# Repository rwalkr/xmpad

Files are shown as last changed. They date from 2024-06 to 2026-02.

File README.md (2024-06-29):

# xmpad - Meeting macropad

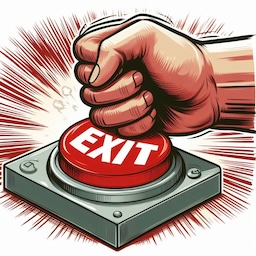
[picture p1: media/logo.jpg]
Exit


Spending too much time in meetings?  Want to exit quickly? Then you need this!

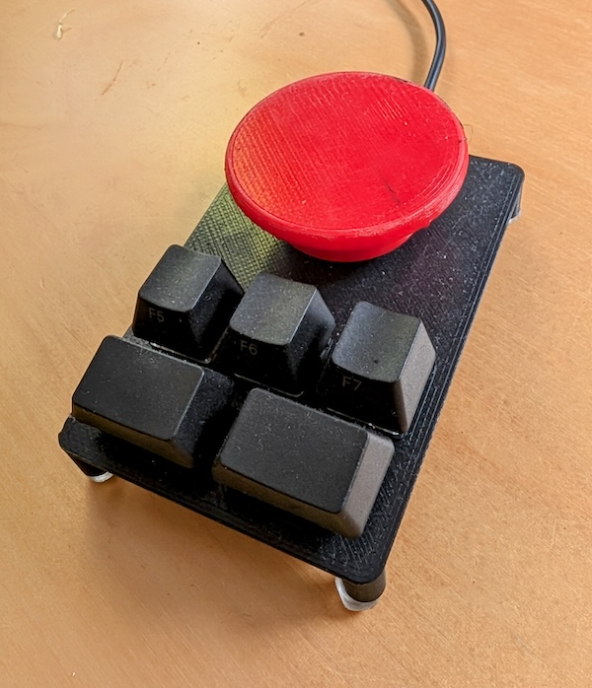
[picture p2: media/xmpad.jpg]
xmpad


Hit the red to button to exit immediately.  Also has buttons for audio mute and video on/off.

xmpad can be configured to emit custom keypresses for each button - change these to fit your meeting software.  The default maps are:

* Red button: Exit - Ctrl+Alt+F12
* Front left: Audio on/off - Ctrl+Alt+F10
* Front right: Video on/off - Ctrl+Alt+F11
* Middle left: Window switch - Alt+Tab
* Middle centre: Close window - Alt+F4
* Middle right: Enter

I've configured global shortcuts in Zoom for these buttons to avoid clashes with other apps.

xmpad is controlled by a Raspberry Pi Pico connected via USB which appears on your computer as an additonal keyboard.  The key switches are standard MX switches, with MX keycaps.  The big red button is glued on top of a MX keycap.

## Build instructions

### Firmware

The firmware is written in rust.  Install the `thumbv6m-none-eabi` toolchain and compile with:

```
cd firmware
cargo build --release
```

Then install by plugging in the Pico in boot mode and running:

```
elf2uf2-rs -d target/thumbv6m-none-eabi/release/xmpad
```

### 3D Print

Print the case and button from the files in `case/`

### BOM

* Printed case and button
* Raspberry Pi Pico
* Micro USB cable
* 6x MX compatible key switches
* 6x MX keycaps (2x 1.5U, 4x 1U)
* Wire
* Screws to attach Pico
* 4x rubber feet

### Wiring

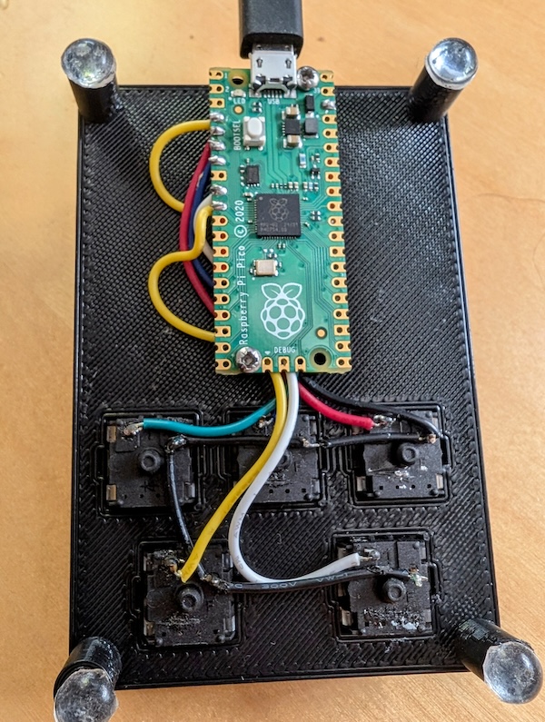
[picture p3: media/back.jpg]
Wiring


* Wire a ground wire across all switches to pin 30 (GND)
* Red button: wire to pin 4 (GPIO2)
* Middle left: wire to pin 5 (GPIO3)
* Middle centre: wire to pin 6 (GPIO4)
* Middle right: wire to pin 7 (GPIO5)
* Front left: wire to pin 9 (GPIO6)
* Front right: wire to pin 10 (GPIO7)

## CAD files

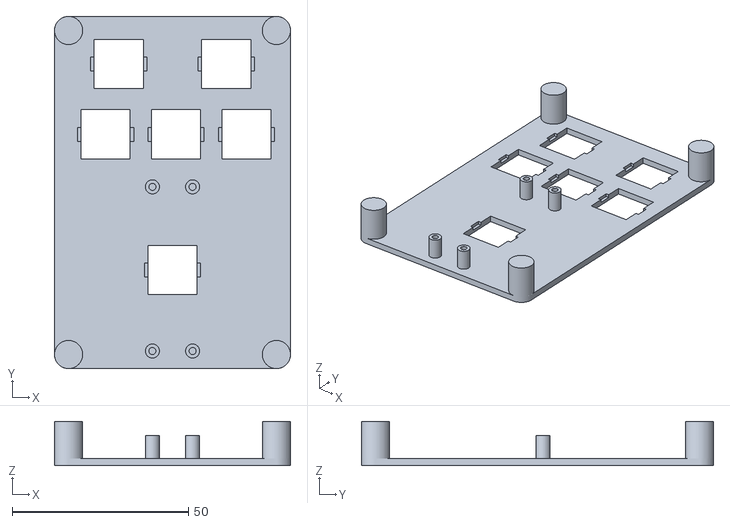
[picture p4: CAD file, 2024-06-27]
case/xmpad.stl
67.0 x 100.0 x 12.5

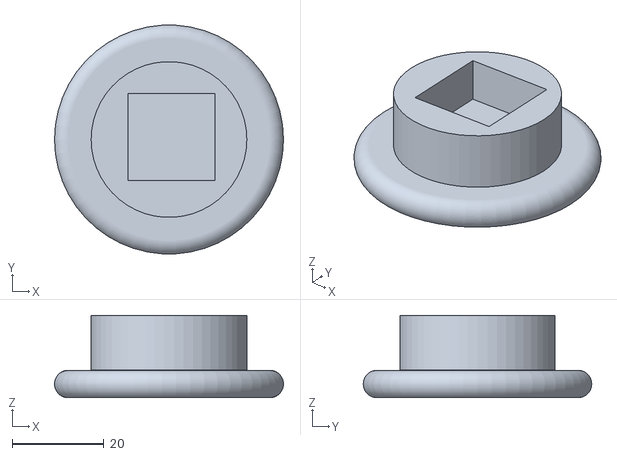
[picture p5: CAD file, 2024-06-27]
case/xmpad_button.stl
50.0 x 49.9 x 18.0

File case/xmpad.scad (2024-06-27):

include <BOSL/constants.scad>
use <BOSL/shapes.scad>

$fn = 50;

U = 19;
K = 14;
KH = 6.5;

SB_D = 50;
SB_T = 6;
SB_H = 18;

PW = 4 + 3*U + 2 + 4;
PD = 4 + 2 * U + 1 + 3 + SB_D + 4;
PH = KH + 4;
PT = 2;

module stop_button () {
  translate([0, 0, SB_H])
  rotate([180, 0, 0])
  color("red") {
    difference() {
      union() {
        //cylinder(h = 6, d = SB_D);
        cyl(h = SB_T, d = SB_D, fillet=3, chamfer = 0, center=false);
        translate([0, 0, SB_T])
          cylinder(r = 17, h = SB_H-SB_T);
      }
      
      translate([-9, -9, SB_H-9])
        cube([19, 19, 9.1]);
    }
  }
}


module key_hole () {
  color("green", 0.1) {
  translate([-K/2, -K/2, -0.1 - 8 + PT]) {
    cube([K, K, 8.2]);
    translate([K/2-2, -1, 6])
      cube([4, K+2, 1.1]);
  }
  }
}

module key_cap (n) {
  color("yellow", 0.6)
  //translate([-n * U / 2, -U / 2, 0])
  prismoid(size1=[n * U, U], size2=[n * U - 4, U - 4], h=8);
//  cube([n * U, U, 8]);
}

module plate () {
    difference() {
      color("blue")
      union() {
        cuboid([PW, PD, 2], fillet=4, edges=EDGES_Z_ALL, center=false);
      }
      
      translate([0, 3 + 1 + 0.5 * U, 0]) {
        translate([4 + 0.75 * U, 0, 0])
          key_hole();
        translate([PW - 4 -  0.75 * U, 0, 0])
          key_hole();
      }
      translate([4, 3 + 1 + U + 1 + 0.5 * U, 0]) {
        translate([0.5 * U, 0, 0])
          key_hole();
        translate([U + 1 + 0.5 * U, 0, 0])
          key_hole();
        translate([2 * U + 2 + 0.5 * U, 0, 0])
          key_hole();
      }
      translate([PW/2, PD - 3 - SB_D/2, 0])
        key_hole();
    }
}

module feet () {
  color("yellow") {
    cube([PW, 3, PH]);
    translate([0, PD - 3, 0])
      difference() {
        cube([PW, 3, PH]);
        translate([PW/2 - 4, -0.1, -0.1])
          cube([8, 3.2, PH - KH + 0.1]);
      }
  }
}

module legs () {
  color("yellow") {
    translate([4, 4, 0])
       cylinder(h = PH, r = 4);
    translate([PW-4, 4, 0])
       cylinder(h = PH, r = 4);
    translate([4, PD-4, 0])
       cylinder(h = PH, r = 4);
    translate([PW-4, PD-4, 0])
       cylinder(h = PH, r = 4);
  }
}

module post () {
   translate([0, 0, PH - KH])
     difference() {
       cylinder(h = KH, d = 4);
       translate([0, 0, -0.1])
       cylinder(h = 3.1, d = 2);
     }
}

module posts () {
  translate([PW/2 - 5.7, PD - 3 - 2, 0])
    post();
  translate([PW/2 + 5.7, PD - 3 - 2, 0])
    post();
  translate([PW/2 - 5.7, PD - 3 - 48.6, 0])
    post();
  translate([PW/2 + 5.7, PD - 3 - 48.6, 0])
    post();
}

  
module pad () {
    translate([0, 0, -PT]) {
      plate();
      translate([0, 0, -PH]) {
        legs();
        posts();
      }
    }
}
  
module preview () {
  translate([PW/2, PD - 3 - SB_D/2, 5])
     stop_button();
  pad();
  
  translate([0, 3 + 1 + 0.5 * U, 2]) {
    translate([4 + 0.75 * U, 0, 0])
      key_cap(1.5);
    translate([PW - 4 -  0.75 * U, 0, 0])
      key_cap(1.5);
    }
  translate([4, 3 + 1 + U + 1 + 0.5 * U, 2]) {
    translate([0.5 * U, 0, 0])
      key_cap(1);
    translate([U + 1 + 0.5 * U, 0, 0])
      key_cap(1);
    translate([2 * U + 2 + 0.5 * U, 0, 0])
      key_cap(1);
  }

}


module print_button () {
  rotate([180, 0, 0])
  stop_button();
}

module print_pad() {
  rotate([180, 0, 0])
  pad();
}


print_pad();
//print_button();
//preview();

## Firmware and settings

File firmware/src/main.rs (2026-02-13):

#![no_std]
#![no_main]

use core::sync::atomic::{AtomicBool, Ordering};

use defmt::*;
use embassy_executor::Spawner;
use embassy_futures::select::{select, Either};
use embassy_rp::bind_interrupts;
use embassy_rp::gpio::{Input, Pull};
use embassy_rp::peripherals::{PIO0, USB};
use embassy_rp::{pio, usb};
use embassy_sync::blocking_mutex::raw::ThreadModeRawMutex;
use embassy_sync::channel::{Channel, Receiver, Sender};
use embassy_time::{block_for, Duration, Instant, Ticker, Timer};
use embassy_usb::class::hid::{
    self, HidReader, HidReaderWriter, HidWriter, ReportId, RequestHandler, State,
};
use embassy_usb::control::OutResponse;
use embassy_usb::{Builder, Config, Handler};
use packed_struct::prelude::*;
use static_cell::StaticCell;
use usbd_human_interface_device::{
    device::keyboard::{BootKeyboardReport, BOOT_KEYBOARD_REPORT_DESCRIPTOR},
    page::Keyboard,
};
use heapless::Vec;

use {defmt_rtt as _, panic_probe as _};

type KbdHidReaderWriter<'a> = HidReaderWriter<'a, usb::Driver<'a, USB>, 1, 25>;
type KbdHidReader<'a> = HidReader<'a, usb::Driver<'a, USB>, 1>;
type KbdHidWriter<'a> = HidWriter<'a, usb::Driver<'a, USB>, 25>;

#[derive(PartialEq)]
enum KbdEvent {
    Press,
    Release
}

type KbdEventQueue = Channel<ThreadModeRawMutex, KbdEvent, 4>;
type KbdEventQueueSender<'a> = Sender<'a, ThreadModeRawMutex, KbdEvent, 4>;
type KbdEventQueueReceiver<'a> = Receiver<'a, ThreadModeRawMutex, KbdEvent, 4>;
type KbdReportQueue = Channel<ThreadModeRawMutex, Keycodes, 4>;
type KbdReportQueueSender<'a> = Sender<'a, ThreadModeRawMutex, Keycodes, 4>;
type KbdReportQueueReceiver<'a> = Receiver<'a, ThreadModeRawMutex, Keycodes, 4>;

mod modifiers {
    pub const SHIFT: u32 = 1;
    pub const CTRL: u32 = 2;
    pub const ALT: u32 = 4;
    pub const GUI: u32 = 8;
}
type Modifiers = u32;

enum KeyAction {
    Simple{ key: Keyboard, m: Modifiers },
    StickyModifiers{ key: Keyboard, m: Modifiers, pre_delay: u64, release_delay: u64 }
}

const KEY_COUNT: usize = 6;
const KEY_ACTIONS: [KeyAction; KEY_COUNT] = [
    KeyAction::Simple { key: Keyboard::F12, m: modifiers::CTRL | modifiers::ALT },
    KeyAction::StickyModifiers { key: Keyboard::Tab, m:  modifiers::ALT, pre_delay: 0, release_delay: 500 },
    KeyAction::StickyModifiers { key: Keyboard::P, m: modifiers::GUI, pre_delay: 50, release_delay: 1000 },
    KeyAction::Simple { key: Keyboard::ReturnEnter, m: 0 },
    KeyAction::Simple { key: Keyboard::F10, m: modifiers::CTRL | modifiers::ALT },
    KeyAction::Simple { key: Keyboard::F11, m: modifiers::CTRL | modifiers::ALT },
];

const MAX_KEYS: usize = KEY_COUNT + 4;
type Keycodes = Vec<Keyboard, MAX_KEYS>;

bind_interrupts!(struct Irqs {
    USBCTRL_IRQ => usb::InterruptHandler<USB>;
    PIO0_IRQ_0 => pio::InterruptHandler<PIO0>;
});

#[embassy_executor::main]
async fn main(spawner: Spawner) {
    let p = embassy_rp::init(Default::default());
    let usb_driver = usb::Driver::new(p.USB, Irqs);

    let key_pins: [Input; KEY_COUNT] = [
        Input::new(p.PIN_2, Pull::Up),
        Input::new(p.PIN_3, Pull::Up),
        Input::new(p.PIN_4, Pull::Up),
        Input::new(p.PIN_5, Pull::Up),
        Input::new(p.PIN_6, Pull::Up),
        Input::new(p.PIN_7, Pull::Up),
    ];

    // Create embassy-usb Config
    // Test PID from https://pid.codes/1209/
    const VID: u16 = 0x1209;
    const PID: u16 = 0x0002;
    let mut config = Config::new(VID, PID);
    config.manufacturer = Some("rwalkr");
    config.product = Some("xmpad");
    config.serial_number = Some(env!("CARGO_PKG_VERSION"));
    config.max_power = 100;
    config.max_packet_size_0 = 64;

    // Create embassy-usb DeviceBuilder using the driver and config.
    // It needs some buffers for building the descriptors.
    static CONFIG_DESCRIPTOR: StaticCell<[u8; 256]> = StaticCell::new();
    let config_descriptor = CONFIG_DESCRIPTOR.init([0; 256]);
    static BOS_DESCRIPTOR: StaticCell<[u8; 256]> = StaticCell::new();
    let bos_descriptor = BOS_DESCRIPTOR.init([0; 256]);
    static MSOS_DESCRIPTOR: StaticCell<[u8; 256]> = StaticCell::new();
    let msos_descriptor = MSOS_DESCRIPTOR.init([0; 256]);
    static CONTROL_BUF: StaticCell<[u8; 64]> = StaticCell::new();
    let control_buf = CONTROL_BUF.init([0; 64]);

    static KBD_HANDLER: StaticCell<KeyboardHandler> = StaticCell::new();
    let kbd_handler = KBD_HANDLER.init(KeyboardHandler::new());

    static DEVICE_HANDLER: StaticCell<USBDeviceHandler> = StaticCell::new();
    let device_handler = DEVICE_HANDLER.init(USBDeviceHandler::new());

    static KBD_HID_STATE: StaticCell<State> = StaticCell::new();
    let kbd_hid_state = KBD_HID_STATE.init(State::new());

    let mut builder = Builder::new(
        usb_driver,
        config,
        config_descriptor,
        bos_descriptor,
        msos_descriptor,
        control_buf,
    );
    builder.handler(device_handler);

    // Create classes on the builder.
    let kbd_hid_config = hid::Config {
        report_descriptor: BOOT_KEYBOARD_REPORT_DESCRIPTOR,
        request_handler: None,
        poll_ms: 60,
        max_packet_size: 64,
    };
    let kbd_hid = KbdHidReaderWriter::new(&mut builder, kbd_hid_state, kbd_hid_config);
    let (kbd_hid_reader, kbd_hid_writer) = kbd_hid.split();

    static KBD_EVENT_QUEUE: StaticCell<Vec<KbdEventQueue, KEY_COUNT>> = StaticCell::new();
    let kbd_event_queue = KBD_EVENT_QUEUE.init((0..KEY_COUNT).map(|_| Channel::new()).collect());
    let kbd_event_senders: Vec<KbdEventQueueSender, KEY_COUNT> = kbd_event_queue.iter().map(|q| q.sender()).collect();
    let kbd_event_receivers: Vec<KbdEventQueueReceiver, KEY_COUNT> = kbd_event_queue.iter().map(|q| q.receiver()).collect();

    static KBD_REPORT_QUEUE: StaticCell<KbdReportQueue> = StaticCell::new();
    let kbd_report_queue = KBD_REPORT_QUEUE.init(Channel::new());
    let kbd_report_sender = kbd_report_queue.sender();
    let kbd_report_receiver = kbd_report_queue.receiver();

    spawner.must_spawn(kbd_scan(key_pins, kbd_event_senders));
    for i in 0..KEY_COUNT {
        spawner.must_spawn(kbd_key_handler(&KEY_ACTIONS[i], kbd_event_receivers[i], kbd_report_sender));
    }
    spawner.must_spawn(kbd_hid_write(kbd_report_receiver, kbd_hid_writer));
    spawner.must_spawn(kbd_hid_read(kbd_hid_reader, kbd_handler));

    let mut usb = builder.build();
    usb.run().await;
}

struct KeyboardHandler {}

impl RequestHandler for KeyboardHandler {
    fn get_report(&mut self, id: ReportId, _buf: &mut [u8]) -> Option<usize> {
        info!("Get report for {:?}", id);
        None
    }

    fn set_report(&mut self, id: ReportId, data: &[u8]) -> OutResponse {
        info!("Set report for {:?}: {=[u8]}", id, data);
        OutResponse::Accepted
    }

    fn set_idle_ms(&mut self, id: Option<ReportId>, dur: u32) {
        info!("Set idle rate for {:?} to {:?}", id, dur);
    }

    fn get_idle_ms(&mut self, id: Option<ReportId>) -> Option<u32> {
        info!("Get idle rate for {:?}", id);
        None
    }
}

impl KeyboardHandler {
    fn new() -> KeyboardHandler {
        KeyboardHandler {}
    }
}

#[embassy_executor::task]
async fn kbd_scan(
    key_pins: [Input<'static>; KEY_COUNT],
    kbd_event_queues: Vec<KbdEventQueueSender<'static>, KEY_COUNT>
) {
    let mut ticker = Ticker::every(Duration::from_millis(1));
    const DEBOUNCE_TICKS: usize = 5;

    let mut pin_states = [false; KEY_COUNT];
    let mut pin_state_counts = [0; KEY_COUNT];
    let mut key_states = [false; KEY_COUNT];
    loop {
        // read pins and update states
        for p in 0..KEY_COUNT {
            let cur_state = key_pins[p].is_low();
            if pin_states[p] != cur_state {
                // pin has changed since last reading - reset counter
                pin_states[p] = cur_state;
                pin_state_counts[p] = 1;
            } else {
                // not changed
                pin_state_counts[p] += 1;
                if pin_state_counts[p] == DEBOUNCE_TICKS {
                    // steady state - update key state
                    info!("kbd_scan: Detected pin {}: {}", p, pin_states[p]);
                    key_states[p] = pin_states[p];
                    let ev = if pin_states[p] {
                        KbdEvent::Press
                    } else  {
                        KbdEvent::Release
                    };
                    kbd_event_queues[p].send(ev).await;
                }
            }
        }

        ticker.next().await;
    }
}

async fn wait_for_press(kbd_event_queue: &KbdEventQueueReceiver<'static>) {
    loop {
        let ev = kbd_event_queue.receive().await;
        if ev == KbdEvent::Press {
            break
        }
    }
}

async fn wait_for_release(kbd_event_queue: &KbdEventQueueReceiver<'static>) {
    loop {
        let ev = kbd_event_queue.receive().await;
        if ev == KbdEvent::Release {
            break
        }
    }
}

fn apply_modifiers(keycodes: &mut Keycodes, m: &Modifiers) {
    if m & modifiers::SHIFT != 0 {
        keycodes.push(Keyboard::LeftShift).unwrap()
    }
    if m & modifiers::CTRL != 0 {
        keycodes.push(Keyboard::LeftControl).unwrap()
    }
    if m & modifiers::ALT != 0 {
        keycodes.push(Keyboard::LeftAlt).unwrap()
    }
    if m & modifiers::GUI != 0 {
        keycodes.push(Keyboard::LeftGUI).unwrap()
    }
}

#[embassy_executor::task(pool_size = KEY_COUNT)]
async fn kbd_key_handler(
    kbd_action: &'static KeyAction,
    kbd_event_queue: KbdEventQueueReceiver<'static>,
    kbd_report_queue: KbdReportQueueSender<'static>,
) {
    match kbd_action {
        KeyAction::Simple{ key, m } => simple_key_handler(key, m, kbd_event_queue, kbd_report_queue).await,
        KeyAction::StickyModifiers { key, m, pre_delay, release_delay } => sticky_mod_key_handler(key, m, pre_delay, release_delay, kbd_event_queue, kbd_report_queue).await,
    }
}

async fn simple_key_handler(
    key: &Keyboard,
    m: &Modifiers,
    kbd_event_queue: KbdEventQueueReceiver<'static>,
    kbd_report_queue: KbdReportQueueSender<'static>,
) {
    loop {
        info!("kbd_state: Waiting for press");
        wait_for_press(&kbd_event_queue).await;

        // send key and modifiers
        let mut keycodes = Keycodes::new();
        keycodes.push(*key).unwrap_or_default();
        apply_modifiers(&mut keycodes, m);
        kbd_report_queue.send(keycodes).await;

        info!("kbd_state: Waiting for release");
        wait_for_release(&kbd_event_queue).await;

        // send empty key set
        kbd_report_queue.send(Keycodes::new()).await;
    }
}

async fn sticky_mod_key_handler(
    key: &Keyboard,
    m: &Modifiers,
    pre_delay: &u64,
    release_delay: &u64,
    kbd_event_queue: KbdEventQueueReceiver<'static>,
    kbd_report_queue: KbdReportQueueSender<'static>,
) {
    let mut mods_held_until = Instant::MAX;
    loop {
        info!("kbd_state: Waiting for press");
        loop {
            let timeout = Timer::at(mods_held_until);
            let ev = select(kbd_event_queue.receive(), timeout).await;
            match ev {
                Either::First(KbdEvent::Press) => {
                    break
                }
                Either::First(KbdEvent::Release) => {
                    // spurious release - keep waiting
                }
                Either::Second(_) => {
                    // deadline elapsed:
                    // send empty keycodes to release mods
                    kbd_report_queue.send(Keycodes::new()).await;
                    mods_held_until = Instant::MAX;
                    // continue waiting
                }
            }
        }

        let mut keycodes = Keycodes::new();
        apply_modifiers(&mut keycodes, m);

        // maybe send modifiers early
        if keycodes.len() > 0 && *pre_delay > 0 {
            kbd_report_queue.send(keycodes.clone()).await;
            block_for(Duration::from_millis(*pre_delay));
        }

        // send the key
        keycodes.push(*key).unwrap_or_default();
        kbd_report_queue.send(keycodes.clone()).await;

        info!("kbd_state: Waiting for release");
        wait_for_release(&kbd_event_queue).await;

        keycodes = Keycodes::new();
        if *release_delay > 0 {
            apply_modifiers(&mut keycodes, m);
            mods_held_until = Instant::now() + Duration::from_millis(*release_delay);
        } else {
            mods_held_until = Instant::MAX;
        }
        kbd_report_queue.send(keycodes.clone()).await;
    }
}

#[embassy_executor::task]
async fn kbd_hid_write(
    kbd_report_queue: KbdReportQueueReceiver<'static>,
    mut kbd_writer: KbdHidWriter<'static>,
) {
    loop {
        info!("hid_writer: Waiting for event");
        let keycodes = kbd_report_queue.receive().await;
        let report = BootKeyboardReport::new(keycodes);

        info!("hid_writer: Sending report");
        match kbd_writer.write(&report.pack().unwrap()).await {
            Ok(()) => {}
            Err(e) => warn!("Failed to send report: {:?}", e),
        };
    }
}

#[embassy_executor::task]
async fn kbd_hid_read(
    kbd_hid_reader: KbdHidReader<'static>,
    kbd_handler: &'static mut KeyboardHandler,
) {
    kbd_hid_reader.run(false, kbd_handler).await;
}

struct USBDeviceHandler {
    configured: AtomicBool,
}

impl USBDeviceHandler {
    fn new() -> Self {
        USBDeviceHandler {
            configured: AtomicBool::new(false),
        }
    }
}

impl Handler for USBDeviceHandler {
    fn enabled(&mut self, enabled: bool) {
        self.configured.store(false, Ordering::Relaxed);
        if enabled {
            info!("Device enabled");
        } else {
            info!("Device disabled");
        }
    }

    fn reset(&mut self) {
        self.configured.store(false, Ordering::Relaxed);
        info!("Bus reset, the Vbus current limit is 100mA");
    }

    fn addressed(&mut self, addr: u8) {
        self.configured.store(false, Ordering::Relaxed);
        info!("USB address set to: {}", addr);
    }

    fn configured(&mut self, configured: bool) {
        self.configured.store(configured, Ordering::Relaxed);
        if configured {
            info!(
                "Device configured, it may now draw up to the configured current limit from Vbus."
            )
        } else {
            info!("Device is no longer configured, the Vbus current limit is 100mA.");
        }
    }
}

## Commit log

2024-11-15 Update key bindings for MS Teams
    [main.rs]
2024-12-19 Revert "Update key bindings for MS Teams"
    Use autohotkey to provide global shortcuts
    This reverts commit 206f0c14ac6a757dabd3c857b959fa7cc1ba0d6f.
    [main.rs]
